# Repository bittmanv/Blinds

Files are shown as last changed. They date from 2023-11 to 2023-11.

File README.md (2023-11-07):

# Blinds
Project covering automated automated blinds with Openhab

Published based on request on Openhab discussion forums

espRoller32 Arduino based sketch 

ShadeEsp32Mini  Kicad project for PCB With MH Mini ESP32 Board 

ShadeEsp32V2 Kicad project for PCB Based on ESP32 Wroom module 

PCBs I have made with my laser engraver with black masked , precision and allign was little bit limiting 

# High level summary

  We have 2 double windows in our kithen/living room. I have bought 2 sun stop blinds and I implemented as part of my home automation to enable privacy on windows coming from street and escpecially on window from south to limit sun which was lights directly to peoples sitting face to window. During summer I use them as aditional temperature and light for room. 
  
  Whole scheduling is based on openhab rules. 

 # Material summary
 JGA25-12V chinese motors with encoder, appox 25rpm  is fine 

 DRV8872  H-Bridge (for each motor) 
 
 Mini360  Buck step down module 
 
 AMS 1117-3.3V regulator 
 
 Some SMD and THT Passive parts according to schematic

 Optionally 
 
 Omron G2MB 5V SSR Relay - we have small 220V led bulb as over window, which is also controlled by automation

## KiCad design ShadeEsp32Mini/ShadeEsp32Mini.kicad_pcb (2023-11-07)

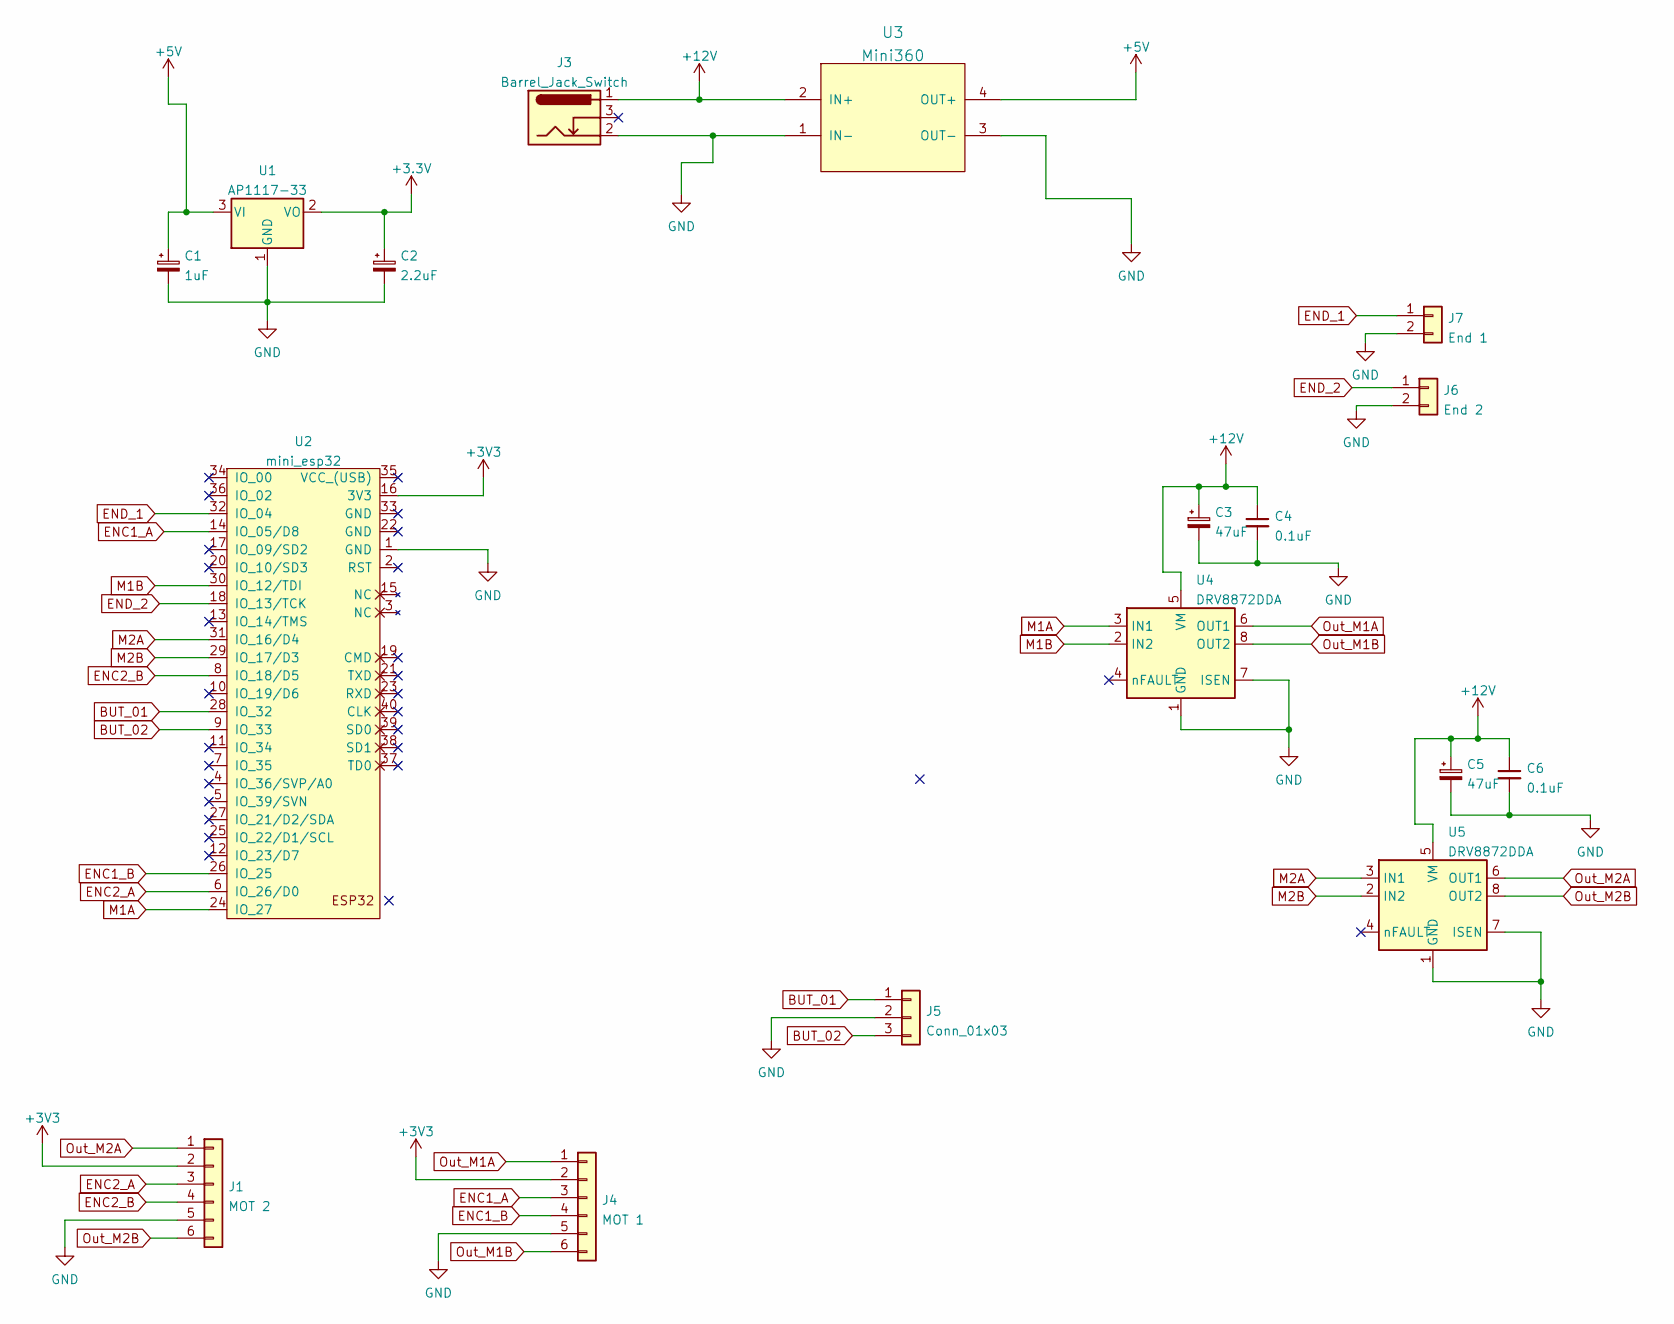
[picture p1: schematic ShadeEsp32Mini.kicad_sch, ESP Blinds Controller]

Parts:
C1: 1uF; CP_Radial_D6.3mm_P2.50mm
C2: 2.2uF; CP_Radial_D6.3mm_P2.50mm
C3, C5: 47uF; CP_Radial_D6.3mm_P2.50mm
C4, C6: 0.1uF; C_1206_3216Metric_Pad1.33x1.80mm_HandSolder
J1: MOT 2; JST_PH_S6B-PH-K_1x06_P2.00mm_Horizontal
J3: Barrel_Jack_Switch; BarrelJack_Horizontal
J4: MOT 1; JST_PH_S6B-PH-K_1x06_P2.00mm_Horizontal
J5: Conn_01x03; JST_XH_S3B-XH-A_1x03_P2.50mm_Horizontal
J6: End 2; JST_XH_S2B-XH-A_1x02_P2.50mm_Horizontal
J7: End 1; JST_XH_S2B-XH-A_1x02_P2.50mm_Horizontal
U1: AP1117-33; SOT-223-3_TabPin2
U2: mini_esp32; ESP32_mini
U3: Mini360; Mini360_step-down
U4, U5: DRV8872DDA; Texas_HTSOP-8-1EP_3.9x4.9mm_P1.27mm_EP2.95x4.9mm_Mask2.4x3.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

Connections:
+5V: C1.1, U1.3 (VI), U3.4 (OUT+)
+12V: C3.1, C4.1, C5.1, C6.1, J3.1, U3.2 (IN+), U4.5 (VM), U5.5 (VM)
BUT_01: J5.1, U2.28 (IO_32)
BUT_02: J5.3, U2.9 (IO_33)
ENC1_A: J4.3, U2.14 (IO_05/D8)
ENC1_B: J4.4, U2.26 (IO_25)
ENC2_A: J1.3, U2.6 (IO_26/D0)
ENC2_B: J1.4, U2.8 (IO_18/D5)
END_1: J7.1, U2.32 (IO_04)
END_2: J6.1, U2.18 (IO_13/TCK)
GND: C1.2, C2.2, C3.2, C4.2, C5.2, C6.2, J1.5, J3.2, J4.5, J5.2, J6.2, J7.2, U1.1 (GND), U2.1 (GND), U3.1 (IN-), U3.3 (OUT-), U4.1 (GND), U4.7 (ISEN), U4.9 (GND), U5.1 (GND), U5.7 (ISEN), U5.9 (GND)
M1A: U2.24 (IO_27), U4.3 (IN1)
M1B: U2.30 (IO_12/TDI), U4.2 (IN2)
M2A: U2.31 (IO_16/D4), U5.3 (IN1)
M2B: U2.29 (IO_17/D3), U5.2 (IN2)
Out_M1A: J4.1, U4.6 (OUT1)
Out_M1B: J4.6, U4.8 (OUT2)
Out_M2A: J1.1, U5.6 (OUT1)
Out_M2B: J1.6, U5.8 (OUT2)

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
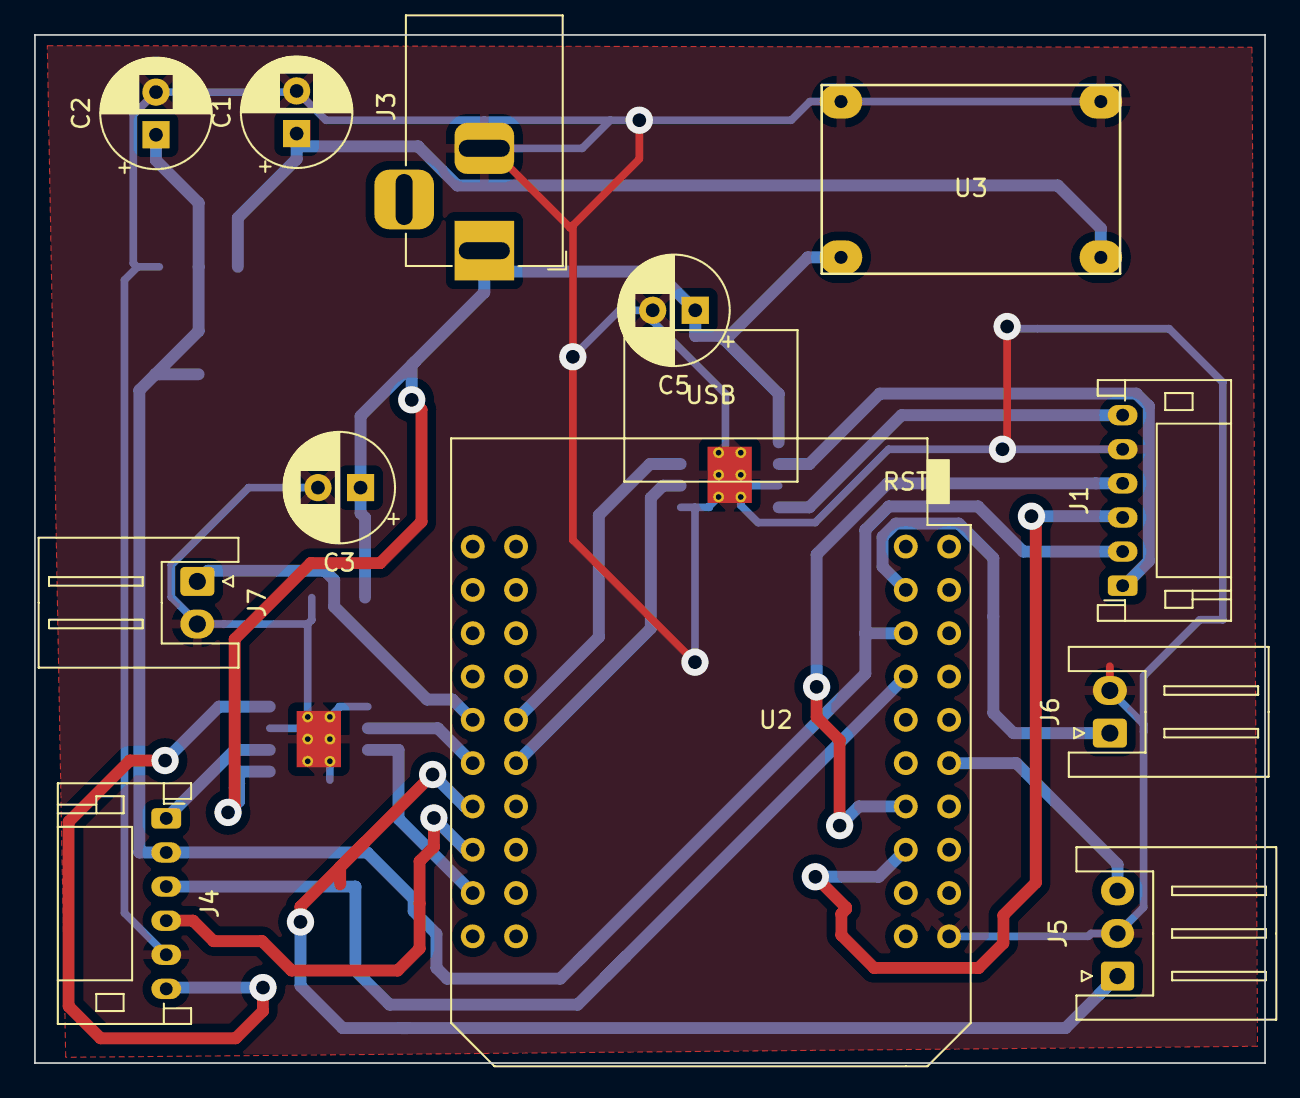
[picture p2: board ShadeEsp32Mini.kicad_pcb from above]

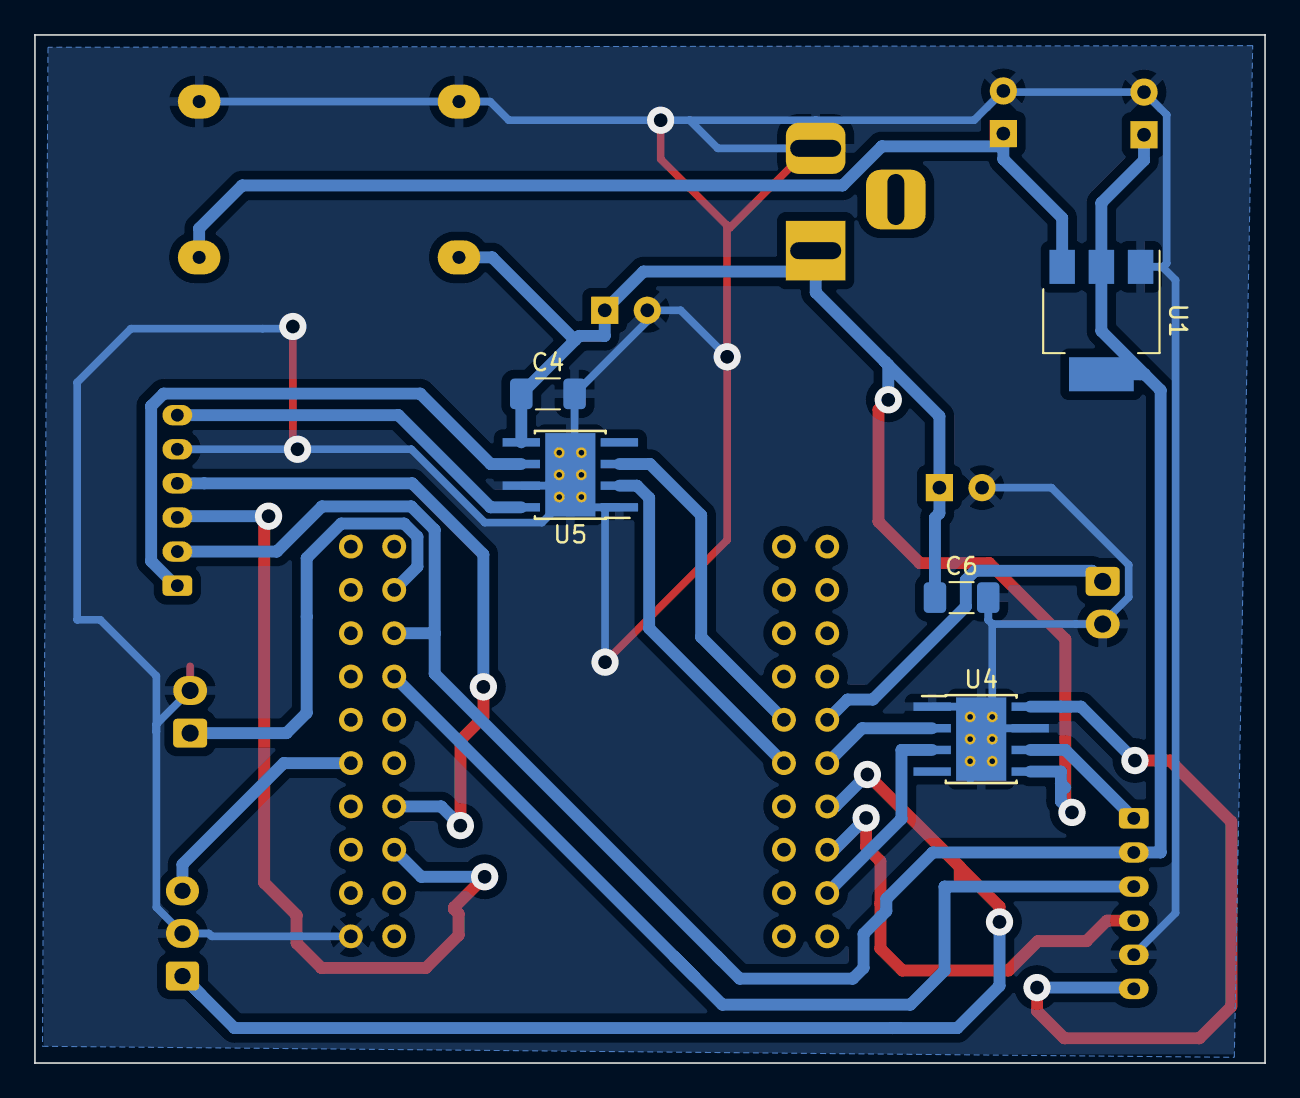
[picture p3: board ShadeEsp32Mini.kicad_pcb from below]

Board: 2 copper layers, 72.2 x 60.3 mm, 17 parts (5 on the bottom side), 20 nets.

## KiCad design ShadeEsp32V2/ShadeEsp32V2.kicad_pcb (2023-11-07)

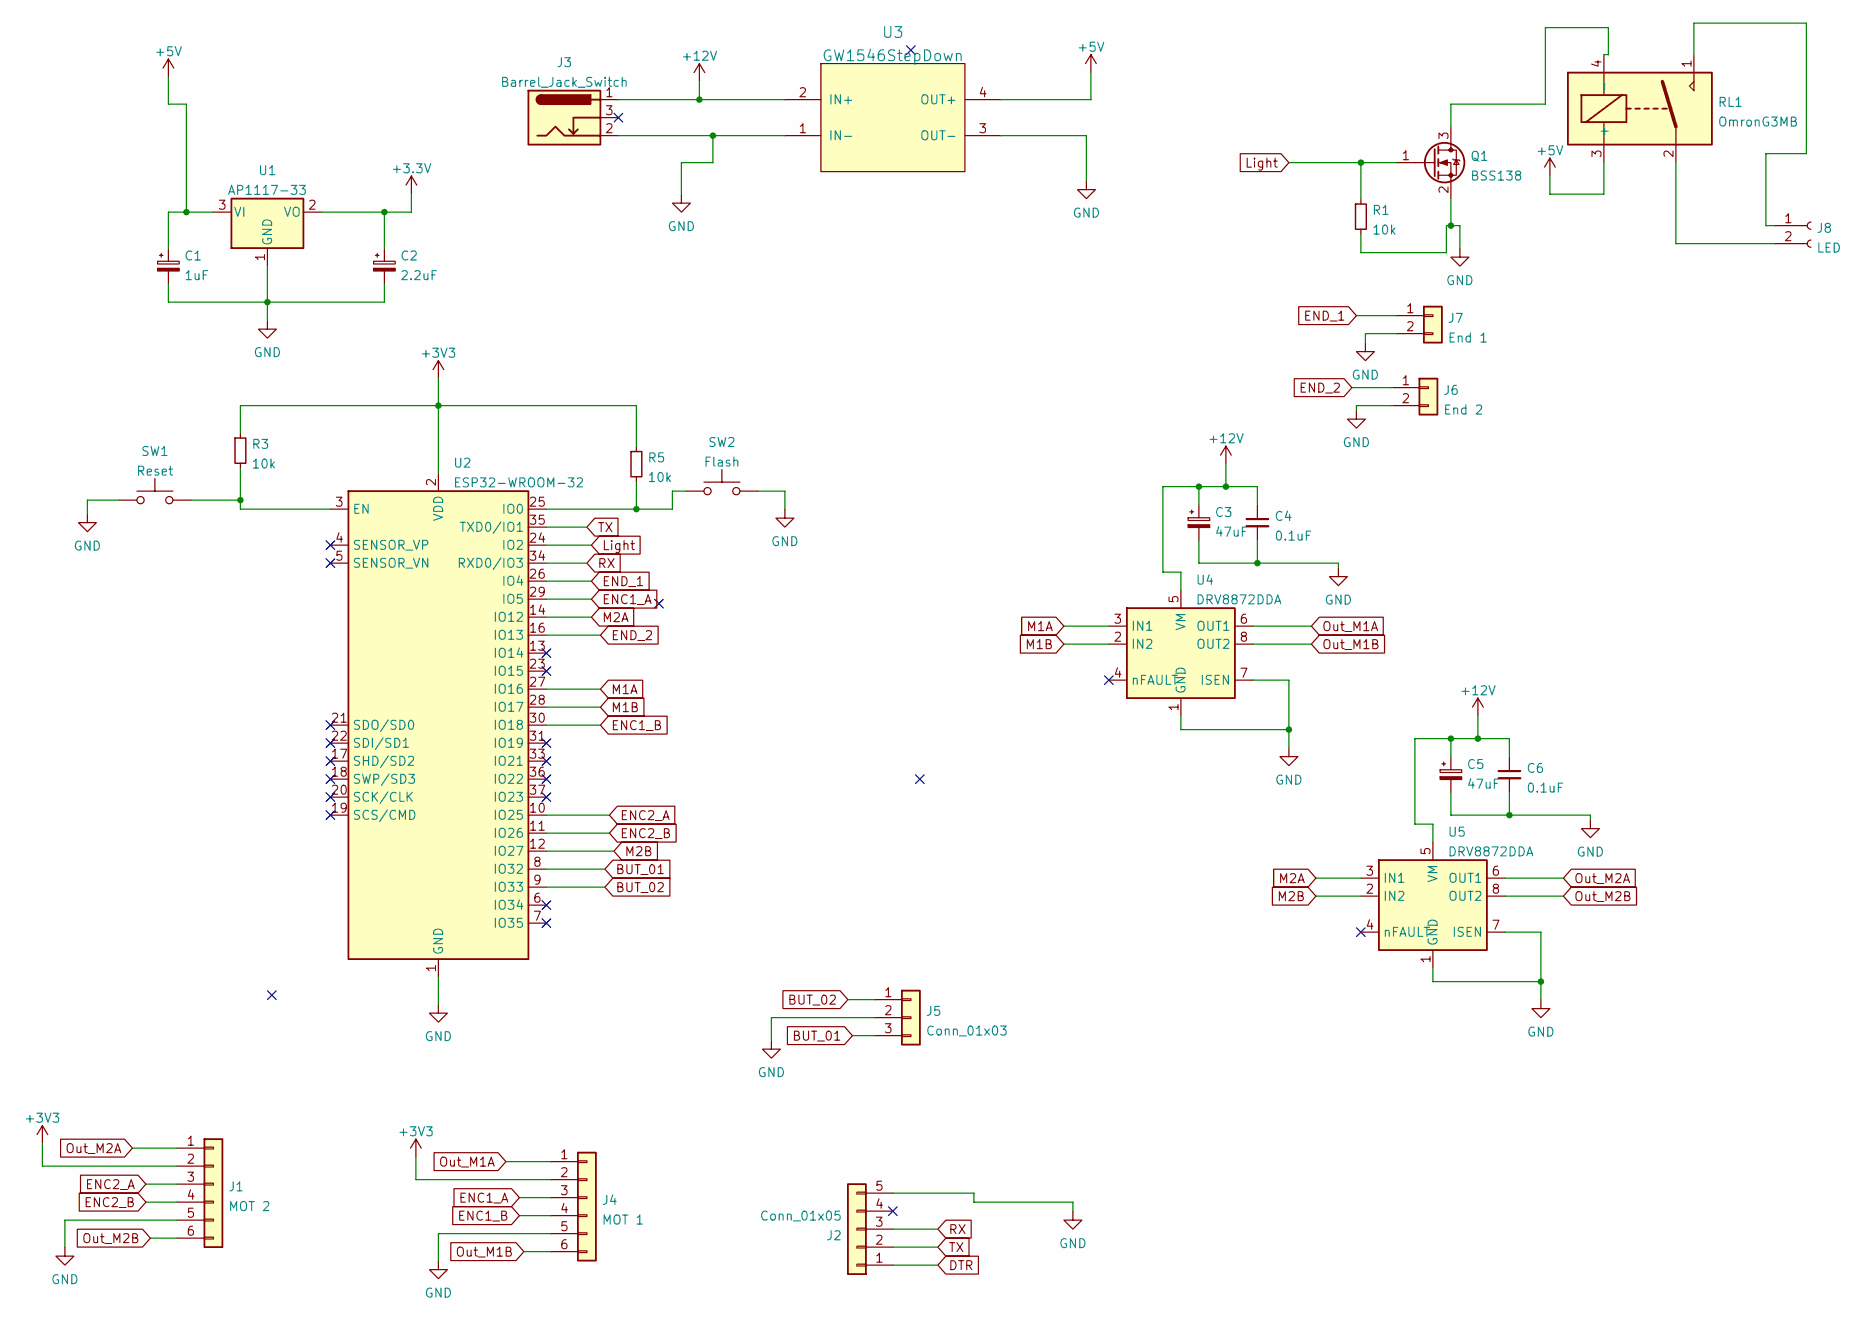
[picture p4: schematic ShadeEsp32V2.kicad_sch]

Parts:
C1: 1uF; CP_Elec_5x4.4
C2: 2.2uF; CP_Elec_6.3x4.9
C3, C5: 47uF; CP_Elec_5x5.3
C4, C6: 0.1uF; C_1206_3216Metric_Pad1.33x1.80mm_HandSolder
J1: MOT 2; JST_PH_S6B-PH-K_1x06_P2.00mm_Horizontal
J2: Conn_01x05; JST_PH_S5B-PH-SM4-TB_1x05-1MP_P2.00mm_Horizontal
J3: Barrel_Jack_Switch; BarrelJack_Horizontal
J4: MOT 1; JST_PH_S6B-PH-K_1x06_P2.00mm_Horizontal
J5: Conn_01x03; JST_PH_S3B-PH-SM4-TB_1x03-1MP_P2.00mm_Horizontal
J6: End 2; JST_PH_S2B-PH-SM4-TB_1x02-1MP_P2.00mm_Horizontal
J7: End 1; JST_PH_S2B-PH-SM4-TB_1x02-1MP_P2.00mm_Horizontal
J8: LED; mkds_1,5-2
Q1: BSS138; SOT-23
R1, R3, R5: 10k; R_1206_3216Metric_Pad1.30x1.75mm_HandSolder
RL1: OmronG3MB; RELAY_G3MB202PDC12
SW1: Reset; SW_Push_1P1T_NO_6x6mm_H9.5mm
SW2: Flash; SW_Push_1P1T_NO_6x6mm_H9.5mm
U1: AP1117-33; SOT-223-3_TabPin2
U2: ESP32-WROOM-32
U3: GW1546StepDown; Mini360_step-down
U4, U5: DRV8872DDA; Texas_HTSOP-8-1EP_3.9x4.9mm_P1.27mm_EP2.95x4.9mm_Mask2.4x3.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

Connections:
+5V: C1.1, RL1.3 (+), U1.3 (VI), U3.4 (OUT+)
+12V: C3.1, C4.1, C5.1, C6.1, J3.1, U3.2 (IN+), U4.5 (VM), U5.5 (VM)
BUT_01: J5.3, U2.8 (IO32)
BUT_02: J5.1, U2.9 (IO33)
DTR: J2.1
ENC1_A: J4.3, U2.29 (IO5)
ENC1_B: J4.4, U2.30 (IO18)
ENC2_A: J1.3, U2.10 (IO25)
ENC2_B: J1.4, U2.11 (IO26)
END_1: J7.1, U2.26 (IO4)
END_2: J6.1, U2.16 (IO13)
GND: C1.2, C2.2, C3.2, C4.2, C5.2, C6.2, J1.5, J2.5, J3.2, J4.5, J5.2, J6.2, J7.2, Q1.2 (S), R1.2, SW1.1, SW2.2, U1.1 (GND), U2.1 (GND), U2.15 (GND), U2.38 (GND), U2.39 (GND), U3.1 (IN-), U3.3 (OUT-), U4.1 (GND), U4.7 (ISEN), U4.9 (GND), U5.1 (GND), U5.7 (ISEN), U5.9 (GND)
Light: Q1.1 (G), R1.1, U2.24 (IO2)
M1A: U2.27 (IO16), U4.3 (IN1)
M1B: U2.28 (IO17), U4.2 (IN2)
M2A: U2.14 (IO12), U5.3 (IN1)
M2B: U2.12 (IO27), U5.2 (IN2)
unnamed: J8.1, RL1.1
unnamed: J8.2, RL1.2
unnamed: Q1.3 (D), RL1.4 (-)
unnamed: R3.2, SW1.2, U2.3 (EN)
unnamed: R5.2, SW2.1, U2.25 (IO0)
Out_M1A: J4.1, U4.6 (OUT1)
Out_M1B: J4.6, U4.8 (OUT2)
Out_M2A: J1.1, U5.6 (OUT1)
Out_M2B: J1.6, U5.8 (OUT2)
RX: J2.3, U2.34 (RXD0/IO3)
TX: J2.2, U2.35 (TXD0/IO1)

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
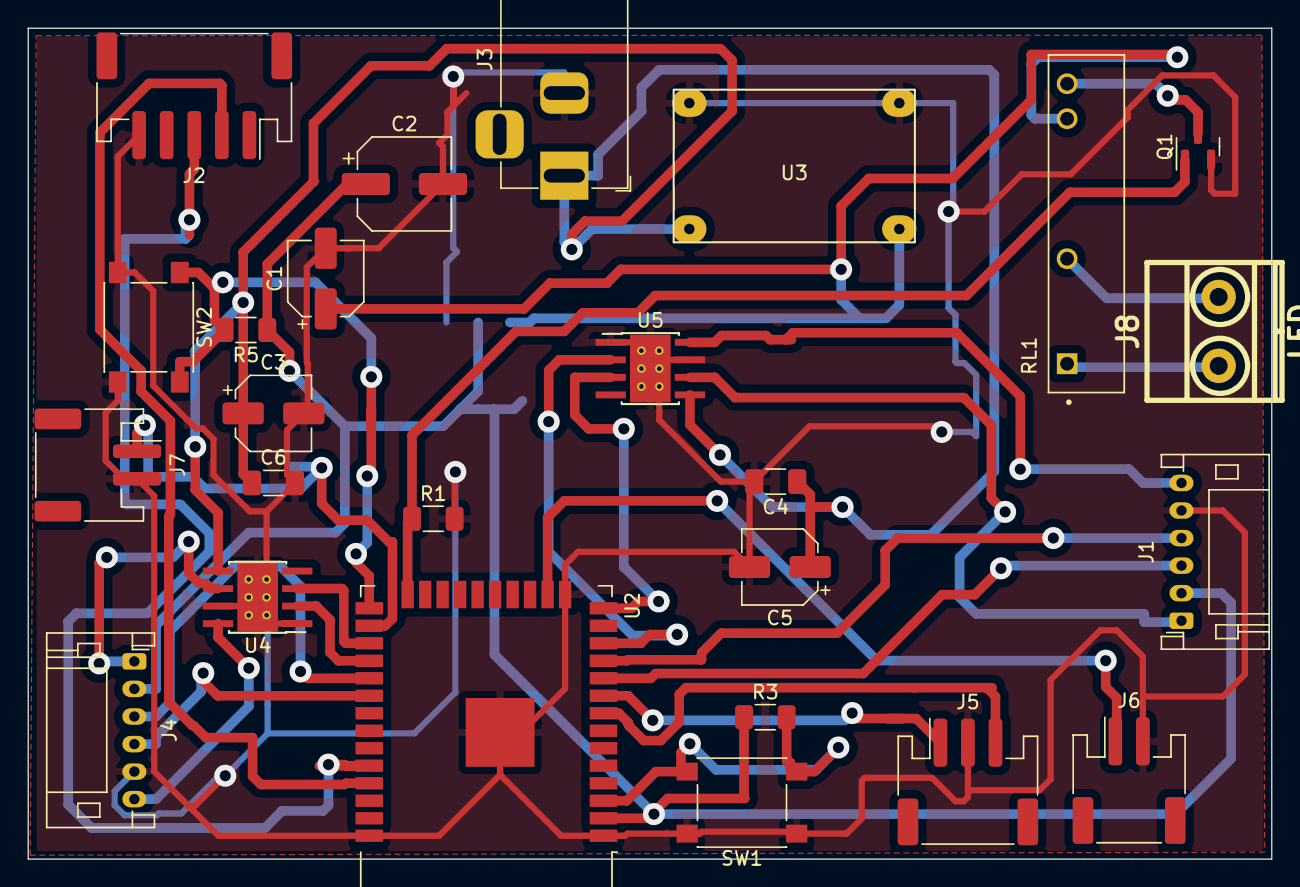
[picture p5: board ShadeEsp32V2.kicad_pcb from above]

Board: 2 copper layers, 90.3 x 60.3 mm, 26 parts (1 on the bottom side), 28 nets.

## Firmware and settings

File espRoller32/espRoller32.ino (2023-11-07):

#include <WiFi.h>
#include <ESPmDNS.h>
#include <WiFiUdp.h>
#include <ArduinoOTA.h>
#include <ArduinoJson.h>
#include <SPIFFS.h>
// MQTT Client
#include <PubSubClient.h>
#include <PIDController.h>

#include <Preferences.h>

Preferences preferences;

#include "RollerControl.h"


struct Config {
  char ssid[64];
  char pwd[32];
  char host[32];
  long len;
  long len2;
  int maxpwm;
  int minpwm;
  int roomNum;
};

struct MotorStatus
{
  int runStatus;
  int32_t lastPosition;
  bool pendingChange=false;
};


 #define LED_BUILTIN 2

const char *filename = "/wificonf.json";  // <- SD library uses 8.3 filenames
const char *motor0stat = "/motor0.json";
const char *motor1stat = "/motor1.json";

IPAddress mqttServer=IPAddress(192,168,1,5);
const char* topicListen = "digitalcomm/101/#" ;

// outbound Mqtt messahe
#define MSG_BUFFER_SIZE  (200)
char msg[MSG_BUFFER_SIZE];

#define MSG_TOPIC_SIZE  200
char topic[MSG_BUFFER_SIZE];



Config config;                         // <- global configuration object

MotorStatus  motorStatus1;
MotorStatus  motorStatus2;

WiFiClient espClient;
PubSubClient client(espClient);


#ifndef STASSID
#define STASSID "xxxxx"
#define STAPSK  "yyyyy"
#endif

const char* ssid = STASSID;
const char* password = STAPSK;

// rotary encoder library
#include <ErriezRotaryFullStep.h>

int motTimerChannelA=3;
int motTimerChannelB=4;
int motTimerChannel2A=1;
int motTimerChannel2B=2;


//  config PCB MH-Mini for motor 2
/*
#define MOT2_PINA 17
#define MOT2_PINB 16
#define MOT2_PWM 3
// int motTimerChannel=0;
//PCB 
#define ENC2_PINA 18
#define ENC2_PINB 26


#define END_STOP2 13
#define PUSH_BUTTON2 33





// config PCB MH-Mini for motor 1

#define MOT_PINA 27
#define MOT_PINB 12
#define MOT_PWM 2

// int motTimerChannelA=3;
// int motTimerChannelB=4;

//PCB 
#define ENC_PINA 5
#define ENC_PINB 25



#define END_STOP 4
#define PUSH_BUTTON 32
*/

// config PCB Wroom module for motor 2

#define MOT2_PINA 27
#define MOT2_PINB 12
#define MOT2_PWM 3
// int motTimerChannel=0;
//PCB 
#define ENC2_PINA 26
#define ENC2_PINB 25


#define END_STOP2 13
#define PUSH_BUTTON2 33





//  config PCB for motor 1

#define MOT_PINA 16
#define MOT_PINB 17
#define MOT_PWM 2

// int motTimerChannelA=3;
// int motTimerChannelB=4;

//PCB 
#define ENC_PINA 5
#define ENC_PINB 18



#define END_STOP 4
#define PUSH_BUTTON 32


#define LIGHT_PIN 2



// motor related variables
enum motorState_t { IDDLE, MOPENING, MCLOSING,  HALL_STOP };
motorState_t motorStatus=IDDLE;



// button variables 
enum buttonCommand_t { GO_UP, STOP, GO_DOWN};
buttonCommand_t  buttonCommand=GO_DOWN;

RollerControl  rollerControl;
RollerControl  rollerControl1;

// #define PROC_PUB_PERIOD 250
// rotary encoder motor 1
RotaryFullStep rotary(ENC_PINA, ENC_PINB);
// rotary encoder motor 2
RotaryFullStep rotary2(ENC2_PINA, ENC2_PINB);
// rotary position for motor/encoder 1
volatile int32_t count = 0;
// rotary position for motor/encoder 2
volatile int32_t count2 = 0;


// Forward declaration
void rotaryInterrupt();
void rotaryInterrupt2();
// encoder definition 

uint32_t lastUpTime=0;
int secsCount=0;
bool fwd=true;
bool initState=true;

#include <OneButton.h>
// init one button button activelow + enable pullup
OneButton debouncer = OneButton(PUSH_BUTTON, true, true); 
OneButton debouncer2 = OneButton(PUSH_BUTTON2, true, true); 

 unsigned int rstCount=0;

#if defined(ARDUINO_ARCH_ESP8266) || defined(ARDUINO_ARCH_ESP32)
ICACHE_RAM_ATTR
#endif
void rotaryInterrupt()
{
    int rotaryState;
   
    // Read rotary state (Counter clockwise) -2, -1, 0, 1, 2 (Clockwise)
    rotaryState = rotary.read();
    //  Serial.print(rotaryState);
    // Count up or down by using rotary speed
    if (rotaryState == 0) {
        // No change
        return;
    } else if (abs(rotaryState) >= 2) {
        count += rotaryState * 2;
    } else {
        count += rotaryState;
    }

    // Limit count to a minimum and maximum value
   /* if (count > 10000) {
        count = 10000;
    }
    if (count < 0) {
        count = 0;
    }
   */
}


#if defined(ARDUINO_ARCH_ESP8266) || defined(ARDUINO_ARCH_ESP32)
ICACHE_RAM_ATTR
#endif
void rotaryInterrupt2()
{
    int rotaryState;
   
    // Read rotary state (Counter clockwise) -2, -1, 0, 1, 2 (Clockwise)
    rotaryState = rotary2.read();
    // Serial.print(rotaryState);
    // Count up or down by using rotary speed
    if (rotaryState == 0) {
        // No change
        return;
    } else if (abs(rotaryState) >= 2) {
        count2 += rotaryState * 2;
    } else {
        count2 += rotaryState;
    }

    // Limit count to a minimum and maximum value
   /* if (count > 10000) {
        count = 10000;
    }
    if (count < 0) {
        count = 0;
    }
   */
}


void setup() {
  Serial.begin(115200);
  Serial.println("Booting");

   //  little fs start
   if(!SPIFFS.begin()){
    Serial.println("An Error has occurred while mounting LittleFS");

    //Print the error on display
    delay(1000);
    return;
  }

  preferences.begin("roller32", false); 

  rstCount=preferences.getUInt("rstCnt",0);
  Serial.print("Soft restart count ");
  Serial.println(rstCount);
  rstCount++;
  preferences.putUInt("rstCnt", rstCount);
  preferences.end();

  
  
  Serial.println(F("Loading configuration..."));
  loadConfiguration(filename, config);
    
  

  // now configure motor1 status
  // initial setup pins for motor 1
  pinMode(MOT_PINA,OUTPUT);
  pinMode(MOT_PINB,OUTPUT);
  // pinMode(MOT_PWM,OUTPUT);
  pinMode(ENC_PINA,INPUT_PULLUP);
  pinMode(ENC_PINB,INPUT_PULLUP);
  // initial setup pins for motor 2
  pinMode(MOT2_PINA,OUTPUT);
  pinMode(MOT2_PINB,OUTPUT);
 // pinMode(MOT2_PWM,OUTPUT);
  pinMode(ENC2_PINA,INPUT_PULLUP);
  pinMode(ENC2_PINB,INPUT_PULLUP);

  pinMode(LED_BUILTIN,OUTPUT);
  // button related to motor 1
  pinMode(END_STOP,INPUT_PULLUP);
  pinMode(PUSH_BUTTON, INPUT_PULLUP);  
  // button related to motor 2
  pinMode(END_STOP2,INPUT_PULLUP);
  pinMode(PUSH_BUTTON2, INPUT_PULLUP);  
  digitalWrite(MOT_PWM,LOW);
  // PWM Setup needed on ESP32 - motor1
  ledcSetup(motTimerChannelA, 5000, 8);
  ledcSetup(motTimerChannelB, 5000, 8);
  // PWM Setup needed on ESP32 - motor2
  ledcSetup(motTimerChannel2A, 5000, 8);
  ledcSetup(motTimerChannel2B, 5000, 8);

   ledcAttachPin(MOT_PINA, motTimerChannelA);
   ledcAttachPin(MOT_PINB, motTimerChannelB);
   ledcAttachPin(MOT2_PINA, motTimerChannel2A);
   ledcAttachPin(MOT2_PINB, motTimerChannel2B);

  pinMode(LIGHT_PIN, OUTPUT);
  digitalWrite(LIGHT_PIN, LOW);
  
  MotorStatus tempStatus;
  
  motorStatus1.runStatus=IDDLE;
  motorStatus1.pendingChange=false;
  if(rstCount<2)
  {
      // start after power resume, loading position from file
      Serial.println("Motor 1 status from file");
      loadMotorStatus(motor0stat, motorStatus1);
      count=motorStatus1.lastPosition;
      // save to prefs to avoid crashes impact for 
      saveMotor0Status(motorStatus1);
  }
  else
  {
    if(digitalRead(END_STOP)==LOW)
    {
      motorStatus1.lastPosition=0;
    }
    else 
    {
      motorStatus1.lastPosition=config.len;
    }
    loadMotor0Status(tempStatus);
    // if last status was saved in iddle state 
    // we can replace position, otherwise we have to keep initial state
    if(tempStatus.runStatus==IDDLE)
    {
      Serial.print("Loaded position M1 ");
      Serial.println(tempStatus.lastPosition);
      motorStatus1.lastPosition=tempStatus.lastPosition;
      motorStatus1.pendingChange=false;
      count=motorStatus1.lastPosition;
    }
  }
  // motor 2 last known position

  motorStatus2.runStatus=IDDLE;
  if(rstCount<2)
  {
      // start after power resume, loading position from file  
      Serial.println("Motor 2 status from file");
      loadMotorStatus(motor1stat, motorStatus2);
      count2=motorStatus1.lastPosition;
      // save to prefs to avoid crashes impact for 
      saveMotor0Status(motorStatus2);
  }
  else
  {
      if(digitalRead(END_STOP2)==LOW)
      {
        motorStatus2.lastPosition=0;
      }
      else 
      {
        motorStatus2.lastPosition=config.len2;
      }
      loadMotor1Status(tempStatus);
      if(tempStatus.runStatus==IDDLE)
      {
        motorStatus2.lastPosition=tempStatus.lastPosition;
        count2=motorStatus2.lastPosition;
        Serial.print("Motor 2 position ");
        Serial.println(count2);
      }
  }
   
   rotary.setSensitivity(200);
   rotary2.setSensitivity(200);
   
   // encoder init end

   // start motor
    digitalWrite(LED_BUILTIN, LOW);
  /* digitalWrite(MOT_PINA,LOW);
   digitalWrite(MOT_PINB,HIGH); */
   // pos_pid.begin(); 
   // pos_pid.tune(1, 2.2, 0);  
   // now full setup
   
   rollerControl.setMotorUpCb(motorUp);
   rollerControl.setMotorDownCb(motorDown);
   rollerControl.setMotorStopCb(stopMotor);
   rollerControl.setGetCounterCb(getCounter);
   rollerControl.setTopEndstopCb(getTopEndStop);
   rollerControl.setPercentMqttCb(publishPercent0);
   rollerControl.setMaxPwm(config.maxpwm);
   rollerControl.setMaxRange(config.len);
   rollerControl.init();

   rollerControl1.setMotorUpCb(motorUp2);
   rollerControl1.setMotorDownCb(motorDown2);
   rollerControl1.setMotorStopCb(stopMotor2);
   rollerControl1.setGetCounterCb(getCounter2);
   rollerControl1.setTopEndstopCb(getTopEndStop2);
   rollerControl1.setPercentMqttCb(publishPercent1);
   rollerControl1.setMaxPwm(config.maxpwm);
   rollerControl1.setMaxRange(config.len2);
   rollerControl1.init();
   attachInterrupt(digitalPinToInterrupt(ENC_PINA), rotaryInterrupt, CHANGE);
  attachInterrupt(digitalPinToInterrupt(ENC_PINB), rotaryInterrupt, CHANGE);

  attachInterrupt(digitalPinToInterrupt(ENC2_PINA), rotaryInterrupt2, CHANGE);
  attachInterrupt(digitalPinToInterrupt(ENC2_PINB), rotaryInterrupt2, CHANGE);
  
   debouncer.attachClick(handleClickA);
   debouncer2.attachClick(handleClickB);
   wifiConnect();

  publishPerc(0,map(count,0, config.len, 0,100));
  publishPerc(1,map(count2,0, config.len2, 0,100));

   
}

void loop() {
  // OTA Handler
   debouncer.tick();
   debouncer2.tick();
  ArduinoOTA.handle();
  if (!client.connected()) {
    reconnect();
  }
  client.loop();


  rollerControl.rollerLoop();
  rollerControl1.rollerLoop();
  // anything to be stored
  if(motorStatus1.pendingChange||motorStatus2.pendingChange)
  {
    if(rollerControl.isIddle()&&rollerControl1.isIddle())
    {
        if(motorStatus1.pendingChange)
         {
           saveMotor0Status(motorStatus1);
           saveMotorStatus(motor0stat,motorStatus1);
           motorStatus1.pendingChange=false;
         }
        if(motorStatus2.pendingChange)
         {
           saveMotor1Status(motorStatus2);
           saveMotorStatus(motor1stat,motorStatus2);
           motorStatus2.pendingChange=false;
         }
    }
  }
  if((lastUpTime+20000)<millis())
  {
    publishUpTime();
    lastUpTime=millis();
  }
  /* if(motorStatus!=IDDLE)
  {
    motorLoop();
  }
  else 
  {
    // nothing special, button handler is in debouncer module
  }
   */
}

static void handleClickA()
{
    motorStatus1.runStatus=MCLOSING;
    if(rollerControl1.isIddle()&&rollerControl.isIddle())
    {
      saveMotor0Status(motorStatus1);
    }
    motorStatus1.pendingChange=true;
    rollerControl.buttonPress();
 
}

static void handleClickB()
{
    motorStatus2.runStatus=MCLOSING;
    if(rollerControl1.isIddle()&&rollerControl.isIddle())
    {
      saveMotor1Status(motorStatus2);
    }
    motorStatus2.pendingChange=true;
    rollerControl1.buttonPress();
 
}


int32_t getCounter()
{
  return(count);
}

int32_t getCounter2()
{
  return(count2);
}


void publishPercent0(uint8_t percent)
{

  publishPerc(0, percent);
}

void publishPercent1(uint8_t percent)
{

  publishPerc(1, percent);
}


int getTopEndStop()
{
   if(digitalRead(END_STOP)==LOW)
      Serial.print("^");
   return(digitalRead(END_STOP));
}

int getTopEndStop2()
{
   if(digitalRead(END_STOP2)==LOW)
      Serial.print("^");
   return(digitalRead(END_STOP2));
}


void stopMotor(int16_t pwm)
{
     Serial.print("S");
      digitalWrite(MOT_PINB,LOW);
      digitalWrite(MOT_PINB,LOW);      
      
      ledcWrite(motTimerChannelA, 0); 
      ledcWrite(motTimerChannelB, 0); 
      motorStatus1.runStatus=IDDLE;
      motorStatus1.lastPosition=count;

      // saveConfig(filename, config);
      // saveMotor0Status(motorStatus1);
}

void stopMotor2(int16_t pwm)
{
     Serial.print("S2 ");
      digitalWrite(MOT2_PINA,LOW);
      digitalWrite(MOT2_PINB,LOW);      
      
      ledcWrite(motTimerChannel2A, 0); 
      ledcWrite(motTimerChannel2B, 0); 
      motorStatus2.runStatus=IDDLE;
      motorStatus2.lastPosition=count2;
      // motor status is saved in async mode 
      // saveConfig(filename, config);
      // saveMotor1Status(motorStatus2);
      

}


void motorDown(int16_t pwm)
{
   Serial.print("D");
   ledcAttachPin(MOT_PINA, motTimerChannelA);
   ledcAttachPin(MOT_PINB, motTimerChannelB);
   ledcWrite(motTimerChannelA, 0); 
   ledcWrite(motTimerChannelB, pwm); 
   // digitalWrite(MOT_PINA,LOW);
   // digitalWrite(MOT_PINB,HIGH); 
   // analogWrite(MOT_PWM,pwm);
   
}

void motorDown2(int16_t pwm)
{
   Serial.print("D2 ");
    ledcAttachPin(MOT2_PINA, motTimerChannel2A);
   ledcAttachPin(MOT2_PINB, motTimerChannel2B);
   
   ledcWrite(motTimerChannel2A, 0); 
   ledcWrite(motTimerChannel2B, pwm); 
   // digitalWrite(MOT_PINA,LOW);
   // digitalWrite(MOT_PINB,HIGH); 
   // analogWrite(MOT_PWM,pwm);
   
}


void motorUp(int16_t pwm)
{
   Serial.print("U");
   
   // analogWrite(MOT_PWM,pwm);
   // motTimerChannel
   ledcAttachPin(MOT_PINA, motTimerChannelA);
   ledcAttachPin(MOT_PINB, motTimerChannelB);
   ledcWrite(motTimerChannelB, 0); 
   ledcWrite(motTimerChannelA, pwm); 
   // digitalWrite(MOT_PINA,HIGH);
   
   
}

void motorUp2(int16_t pwm)
{
   Serial.print("U2 ");
   Serial.println(pwm);
   
   // analogWrite(MOT_PWM,pwm);
   // motTimerChannel
   // ledcAttachPin(MOT2_PINA, motTimerChannel2A);
   // ledcAttachPin(MOT2_PINB, motTimerChannel2B);
   // ledcDetachPin(MOT2_PINA);
   // digitalWrite(MOT2_PINA,HIGH);
   ledcWrite(motTimerChannel2B, 0); 
   ledcWrite(motTimerChannel2A, pwm); 
   // digitalWrite(MOT_PINA,HIGH);
   
   
}

void loadConfiguration(const char *filename, Config &config) {
  // Open file for reading
  // File file = SPIFFS.open(filename,"r");
  File file = SPIFFS.open(filename);

  // Allocate a temporary JsonDocument
  // Don't forget to change the capacity to match your requirements.
  // Use arduinojson.org/v6/assistant to compute the capacity.
  StaticJsonDocument<512> doc;

  // Deserialize the JSON document
  DeserializationError error = deserializeJson(doc, file);
  if (error)
    Serial.println(F("Failed to read file, using default configuration"));
  Serial.print("Loaded ssid");
  const char* ssid = doc["ssid"];
  Serial.println(ssid);
  // Copy values from the JsonDocument to the Config
  config.len = doc["len"] | 2900;
  config.len2 = doc["len2"] | 2900;
  config.roomNum = doc["roomNum"] | 99;
  Serial.print("Room num ");
  Serial.println(config.roomNum );
  config.maxpwm=doc["maxpwm"] | 200;
  config.minpwm=doc["minpwm"] | 128;
  mqttServer[0]=doc["mqtt"][0] | 192;
  mqttServer[1]=doc["mqtt"][1] | 168;
  mqttServer[2]=doc["mqtt"][2] | 1;
  mqttServer[3]=doc["mqtt"][3] | 1;
  
  
  strlcpy(config.ssid,                  // <- destination
          doc["ssid"] | "xxxx",  // <- source
          sizeof(config.ssid));         // <- destination's capacity

  strlcpy(config.pwd,                  // <- destination
          doc["pwd"] | "yyyy",  // <- source
          sizeof(config.pwd));         // <- destination's capacity


  strlcpy(config.host,                  // <- destination
          doc["host"] | "espRoller1",  // <- source
          sizeof(config.host));         // <- destination's capacity

  
  // Close the file (Curiously, File's destructor doesn't close the file)
  file.close();
}

void saveConfig(const char *filename, Config &config) {
 
  // Delete existing file, otherwise the configuration is appended to the file
  // SD.remove(filename);

  // Open file for writing
  /*File file = LittleFS.open(filename,"w");
  if (!file) {
    Serial.println(F("Failed to create file"));
    return;
  }
  */
  // Allocate a temporary JsonDocument
  // Don't forget to change the capacity to match your requirements.
  // Use arduinojson.org/assistant to compute the capacity.
  StaticJsonDocument<512> doc;

  // Set the values in the document
  doc["ssid"] = config.ssid;
  doc["pwd"] = config.pwd;
  doc["host"] = config.host;
  doc["roomNum"] = config.roomNum;
  doc["len"]= config.len;
  doc["len2"]= config.len;
  doc["maxpwm"] = config.maxpwm;
  doc["minpwm"] = config.minpwm;
  doc["mqtt"][0]= mqttServer[0];
  doc["mqtt"][1]= mqttServer[1];
  doc["mqtt"][2]= mqttServer[2];
  doc["mqtt"][3]= mqttServer[3];
  serializeJson(doc, Serial);
  //doc.prettyPrint(Serial);
  // Serialize JSON to file
  /*if (serializeJson(doc, file) == 0) {
    Serial.println(F("Failed to write to file"));
  }

  // Close the file */
 // file.close();


}

void loadMotorStatus(const char *filename, MotorStatus &config) {
  // Open file for reading
  // File file = SPIFFS.open(filename,"r");
  if(!SPIFFS.exists(filename))
  {
      Serial.println("File not found");
      saveMotorStatus(filename, config);
  }
  File file = SPIFFS.open(filename);

  // Allocate a temporary JsonDocument
  // Don't forget to change the capacity to match your requirements.
  // Use arduinojson.org/v6/assistant to compute the capacity.
  StaticJsonDocument<512> doc;

  // Deserialize the JSON document
  DeserializationError error = deserializeJson(doc, file);
  if (error)
    Serial.println(F("Failed to read file, using default configuration"));
  Serial.print("Loaded ssid");
  const char* ssid = doc["run"];
  Serial.println(ssid);
  // Copy values from the JsonDocument to the Config
  config.runStatus = doc["runStatus"] | IDDLE;
  config.lastPosition = doc["lastPosition"] | 99;

  file.close();
}


void saveMotorStatus(const char *filename, MotorStatus &config) {

  if(SPIFFS.exists(filename))
  {
      Serial.print("Deleting file ");
      Serial.println(filename);
      SPIFFS.remove(filename);
  }
  File file = SPIFFS.open(filename, FILE_WRITE);

   StaticJsonDocument<512> doc;

  // Set the values in the document
  doc["runStatus"] = config.runStatus;
  doc["lastPosition"] = config.lastPosition;


  if (serializeJson(doc, file) == 0) {
    Serial.println(F("Failed to write to file"));
  }

  file.close();
  serializeJson(doc, Serial);
}
 

void loadMotor0Status(MotorStatus &config) {
  // Open file for reading
  // File file = SPIFFS.open(filename,"r");
  Serial.print("Loading Prefs");
  preferences.begin("roller32", false); 
  int8_t prefExists=preferences.getChar("motor0exists", 0);
  if(prefExists==0)
  {
      saveMotor0Status( config);
  }
  config.runStatus=preferences.getChar("m0S", IDDLE);
  config.lastPosition=preferences.getLong("m0P",0);
  Serial.print("Loaded position ");
  Serial.println(config.lastPosition);
preferences.end();
}


void saveMotor0Status(MotorStatus &config) {
  preferences.begin("roller32", false); 
  Serial.println("Saving Prefs");
  preferences.putChar("motor0exists",1);
  preferences.putChar("m0S", config.runStatus);
  preferences.putLong("m0P", config.lastPosition);
  Serial.print("Saving position ");
  Serial.println(config.lastPosition);
  preferences.end();
}

void loadMotor1Status(MotorStatus &config) {
  // Open file for reading
  // File file = SPIFFS.open(filename,"r");
  preferences.begin("roller32", false); 
  Serial.print("Loading Prefs");
  int8_t prefExists=preferences.getChar("motor1exists", 0);
  if(prefExists==0)
  {
      saveMotor1Status( config);
  }
  config.runStatus=preferences.getChar("m1S", IDDLE);
  config.lastPosition=preferences.getLong("m1P",0);
  Serial.print("Loaded position ");
  Serial.println(config.lastPosition);
preferences.end();
}


void saveMotor1Status(MotorStatus &config) {
  preferences.begin("roller32", false); 
  Serial.println("Saving Prefs");
  preferences.putChar("motor1exists",1);
  preferences.putChar("m1S", config.runStatus);
  preferences.putLong("m1P", config.lastPosition);
  Serial.print("Saving position ");
  Serial.println(config.lastPosition);
  preferences.end();

 
  
}
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

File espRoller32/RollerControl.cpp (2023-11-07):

#include "RollerControl.h"

RollerControl::RollerControl()
{
    getCounterValid=false;
}


RollerControl::~RollerControl()
{
     // no special activity in destructor
}

void RollerControl::setGetCounterCb(getCounterFunc_t callbackfunc_new)
{
   counterCallBackFunc=callbackfunc_new;
   getCounterValid=true;
}


void RollerControl::setMotorUpCb(setMotorDirFunc_t callbackfunc_new)
{
     motorUpFunc=callbackfunc_new;
     motorUpValid=true;
}

void RollerControl::setMotorDownCb(setMotorDirFunc_t callbackfunc_new)
{
     motorDownFunc=callbackfunc_new;
     motorDownValid=true;
  
}

void RollerControl::setMotorStopCb(setMotorDirFunc_t callbackfunc_new)
{
     motorStopFunc=callbackfunc_new;
     motorStopValid=true;
}

void RollerControl::setPercentMqttCb(publishPercent_t callbackfunc_new)
{
     publishPercentFunc=callbackfunc_new;
     publishPercentValid=true;
}

void RollerControl::setTopEndstopCb(getEndStopFunc_t callbackfunc_new)
{
     getTopEndstopFunc=callbackfunc_new;
     getTopEndstopValid=true;
}

int  RollerControl::getTopEndstop()
{
    if(getTopEndstopValid)
    {
      return getTopEndstopFunc();
    }
    else
      return LOW;
}
void RollerControl::setMaxPwm(int16_t newMaxPwm)
{
  maxPwm=newMaxPwm;
}


int16_t RollerControl::getSpeed(uint32_t currentMillis)
{
    uint16_t retVal=motSpeed;
    // int32_t currPos;
    currentPosition=getCurrentPosition();
    
    if((lastSpeedCalc+PID_PERIOD)<currentMillis)
    {
         
             // currPos=currentPosition;
             // Serial.print(F("s"));
         Serial.print(F(" sCS "));
         Serial.print(lastSpeedPos);
         Serial.print(F(";"));
         Serial.print(currentPosition);
         Serial.print(F(" ")); 
         retVal=abs(currentPosition-lastSpeedPos);
         lastSpeedPos=currentPosition;   
         motSpeed=retVal;
         Serial.print(" ms ");
         Serial.println(motSpeed);
    }
    return retVal;
}

void RollerControl::resetSpeed()
{
        
         lastSpeedPos=currentPosition;
         lastSpeedCalc=millis();
         motSpeed=50;
         
}


void RollerControl::gotoPercentage(uint8_t percentage)
{
   // first refresh current position of motor
   currentPosition=getCurrentPosition();
   Serial.print("Current enc position");
   Serial.println(currentPosition);
   // first map percentage to requested position of motor
   requestedPosition=map(percentage,0,100,0,maxRange);
   Serial.print(" goto ");
   Serial.println(requestedPosition);
   // set properties of PID Controller
   pos_pid.setpoint((double) requestedPosition);
   pos_pid.limit(-maxPwm, maxPwm);
   // now set motor status to proper value
   // in case of opening we are checking end stop  
    resetSpeed();
     if(requestedPosition>currentPosition)
    {
       motorStatus=MCLOSING;
       motorDown(maxPwm);
    }
    else if(requestedPosition<currentPosition) 
    {
      motorStatus=MOPENING;
      motorUp(maxPwm);
    }
    // nowreset speed
    
    
    // current millis in PID Call will allow motor to start
    lastPwm=maxPwm;
    lastPercPub=lastPidCall=millis();
    // now main loop 
    rollerLoop();
}


void RollerControl::setMaxRange(int32_t newMaxRange)
{
    maxRange=newMaxRange;
}


void RollerControl::init()
{
   pos_pid.begin(); 
   pos_pid.tune(1, 2.2, 0);  
   motorStatus=IDDLE;
   
}

int32_t RollerControl::getCurrentPosition()
{
   int32_t tempPos=0;
   if(getCounterValid)
   {
       tempPos=counterCallBackFunc();
   }
   return tempPos;
}

void RollerControl::stopMotor(int pwm)
{
    if(motorStopValid)
    {
       motorStopFunc(pwm);
    }
    motorStatus=IDDLE;
    stoppedAt=millis();
}

void RollerControl::motorUp(int pwm)
{
   if(motorUpValid)
   {
      motorUpFunc(pwm);
   }
  
}

void RollerControl::motorDown(int pwm)
{
   if(motorDownValid)
   {
      motorDownFunc(pwm);
   }
}

void RollerControl::publishPercent(uint8_t percent)
{
    if(publishPercentValid)
    {
       publishPercentFunc(percent);
    }
}

bool RollerControl::isIddle()
{
    switch(motorStatus)
    {
      case IDDLE:
         if(millis()>(stoppedAt+500))
           return true;
          else
            return false;
        break;
      default :
         return false;

    }
  
    // return motorStatus==IDDLE;
}
void RollerControl::rollerLoop()
{
    uint32_t currentMs=millis();
    int16_t motSpeed;

    // in case, when motor is iddle, do nothing
    if(motorStatus==IDDLE)
       return;

    if(currentMs>(lastPercPub+PROC_PUB_PERIOD))
    {
         publishPercent(map(currentPosition,0,maxRange,0,100));
         lastPercPub=currentMs;
    }
    // first handling of endstops
    switch(motorStatus)
    {
       case MOPENING:
        if(getTopEndstop()==LOW)
        {
             stopMotor(0);
             currentPosition=0;
             publishPercent(0);
             // TODO : Reset counter method button management
        }
    }

    // main motor control function
    switch(motorStatus)
    {
        case MOPENING:
        case MCLOSING:
           currentPosition=getCurrentPosition();
           // TODO: Handle call back for publishing current position during movement
           if((lastPidCall+PID_PERIOD)<currentMs)
           {
                // get current motor speed
                motSpeed=getSpeed(currentMs);
                // next pid call after some time
                lastPidCall=currentMs;
                 Serial.print("sp ");
                // motSpeed=getSpeed(lastPIDCall);
                Serial.print(motSpeed);
                
                Serial.print(" curPos ");
                Serial.println(currentPosition);
                // int motorPwm=pos_pid.compute((double)currentPosition, GRAPH, VERBOSE);
                int motorPwm=pos_pid.compute((double)currentPosition);
                // if is there new pwm 
                 Serial.print(" pwm ");
                 Serial.println(motorPwm);

                if(motorPwm!=lastPwm)
                {
                    lastPwm=motorPwm;
                    if(motorPwm>0)
                    {
                       motorDown(abs(motorPwm));
                    }
                    else if(motorPwm<0)
                    {
                        motorUp(abs(motorPwm));
                    }
                    else
                    {
                      stopMotor(motorPwm);
                      motorStatus=IDDLE;
                      publishPercent(map(currentPosition,0,maxRange,0,100));

                      // TODO: Button handling 
                      /*
                       * button command template
                       */
                       
                        if(currentPosition>100)
                            buttonCommand=GO_UP;
                          else
                            buttonCommand=GO_DOWN;
                    }
                }
                // now stop based on speed and requested position
                int posDiff=abs(requestedPosition-currentPosition);
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

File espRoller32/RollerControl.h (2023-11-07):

/**
 *  class for generic motor controlling
 * 
 */

#ifndef rollerController_h

#define rollerController_h


#include <Arduino.h>

// class for PID Controlller 
#include <PIDController.h>


#define PID_PERIOD 100
#define PROC_PUB_PERIOD 1000



class RollerControl {

  public:

    // Constructor / desctructor

    RollerControl();

    virtual ~RollerControl();

      
    // TODO:: delete this example
    // typedef void (*cbfunc_t) (libClass *pInstance);

     enum motorState_t { IDDLE, MOPENING, MCLOSING,  HALL_STOP };    
     // button variables 
      enum buttonCommand_t { GO_UP, STOP, GO_DOWN};

    // get counter method to read current state of motor
    typedef int32_t (*getCounterFunc_t) ();

    // function type for setting pwm on motor
    typedef void (*setMotorDirFunc_t) (int16_t pwm);

    // function type for procent publishing call back
    typedef void (*publishPercent_t) (uint8_t percent);

     // function for reading endstops
     typedef int (*getEndStopFunc_t) ();
    

    // method to set motor counter 
    void setGetCounterCb(getCounterFunc_t callbackfunc_new);

    // methods to set motor control functions

    void setMotorUpCb(setMotorDirFunc_t callbackfunc_new);
    void setMotorDownCb(setMotorDirFunc_t callbackfunc_new);
    void setMotorStopCb(setMotorDirFunc_t callbackfunc_new);

    // callback to read end stop
    void setTopEndstopCb(getEndStopFunc_t callbackfunc_new);

    void setPercentMqttCb(publishPercent_t callbackfunc_new);
     
    // method receive command from button
    void buttonPress();

    // main method for controlling activity
    void rollerLoop();

    // command to go for specific percentage
    void gotoPercentage(uint8_t percentage);
    uint8_t getCurrentPercentage();

    void setMaxPwm(int16_t newMaxPwm);

    // set maximum range in motor steps 
    void setMaxRange(int32_t newMaxRange);
    void stopNow();
    
    void init();
    
     // speed calculation  
    int16_t getSpeed(uint32_t currentMillis);

    bool isIddle();
    
    
      
  private :
    PIDController pos_pid;
    uint32_t lastPidCall=0;
    int32_t maxRange=100;
    // requested position
    int32_t requestedPosition=0;
    // last known position for PID Calls 
    int32_t lastKnownPosition=0;
    // max pwm for motor operation
    int16_t maxPwm=255;
    // last calculated pwm
    int16_t lastPwm=0;
    // timestamp of motor stop to preventints durinf SPIFFS ops
    uint32_t stoppedAt;
    
    
    // last calculated speed 
    int16_t motSpeed=0;

     int32_t lastSpeedPos=0;
     uint32_t lastSpeedCalc=millis();
     int32_t currentPosition=0;

     buttonCommand_t  buttonCommand=GO_DOWN;

     uint32_t lastPercPub=0;
    
    motorState_t motorStatus=IDDLE;
    bool getCounterValid=false;
    
    getCounterFunc_t counterCallBackFunc;

    bool motorUpValid=false;
    setMotorDirFunc_t motorUpFunc;

    bool motorDownValid=false;
    setMotorDirFunc_t motorDownFunc;

    bool motorStopValid=false;
    setMotorDirFunc_t motorStopFunc;

     bool getTopEndstopValid=false;
     getEndStopFunc_t getTopEndstopFunc;

     bool publishPercentValid=false;
     publishPercent_t  publishPercentFunc;
     
    void resetSpeed();

    int32_t getCurrentPosition();
    int  getTopEndstop();

    void stopMotor(int pwm);
    void motorUp(int pwm);
    void motorDown(int pwm);

    void publishPercent(uint8_t percent);
    

};


#endif
